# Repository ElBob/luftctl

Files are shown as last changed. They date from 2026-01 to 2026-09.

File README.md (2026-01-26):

# luftctl

Small ESP32-C3 controller board to power two 12V PWM fans from a single USB-C plug.



## hardware

Schematic and PCB design can be found in [`hardware/`](hardware/). It is a KiCAD 6 project.

The schematic is available as [a PDF](schematic.pdf).

For hand-soldering, you can use the [interactive BOM viewer](hardware/ibom.html).

## firmware

### micropython

The first simple test just loops through {`5V/off`, `5V/on`, `12V/off`, `12V/on`} with every button press.

Download MicroPython from [micropython.org/download/esp32c3-usb/](https://micropython.org/download/esp32c3-usb/) and flash it with:

```
esptool.py --chip esp32c3 --port /dev/ttyACM0 erase_flash
esptool.py --chip esp32c3 --port /dev/ttyACM0 --baud 460800 write_flash -z 0x0 esp32c3-*.bin
```

Then install a virtualenv with `adafruit-ampy` and upload the [`main.py`](main.py):

```
ampy -p /dev/ttyACM0 put main.py
ampy -p /dev/ttyACM0 reset --hard
```

The red LED will blink upon every state change.

### esphome

Since the ESP32-C3 is easily supported by ESPHome, you can also add it in your HomeAssistant automation using the [provided example YAML](esphome/luftctl.yaml).

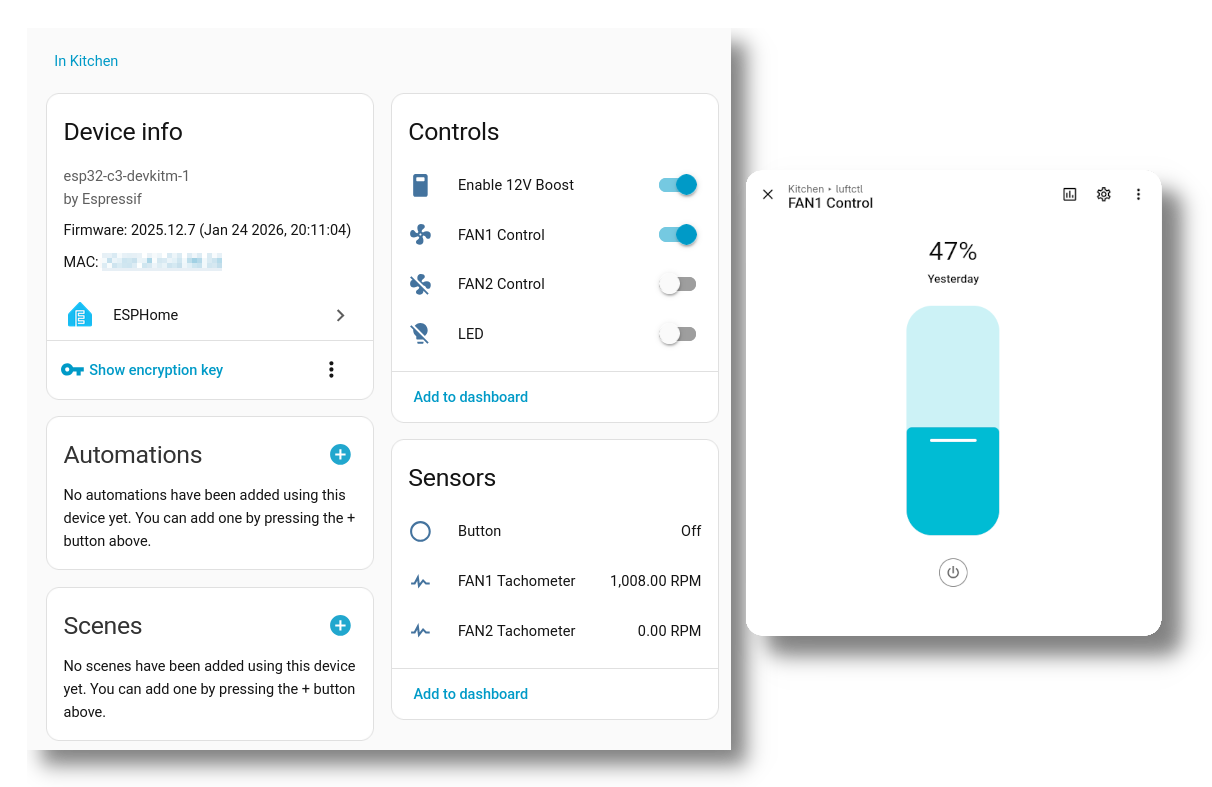
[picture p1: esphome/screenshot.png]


## images











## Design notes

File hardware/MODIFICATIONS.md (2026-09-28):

# luftctl — design change: USB‑C PD 12 V input + GPIO breakout

## ✅ Implementation status (branch `usbc-pd-12v-and-gpio-breakout`)

**Both changes are implemented in the schematic** (`luftctl.kicad_sch`) and
verified: the netlist was re-exported and every rail/net checked, and ERC is at
the project's baseline (the remaining violations are pre‑existing
`lib_symbol_mismatch` from this project's custom symbols, plus one benign
"power pin not driven" on the CH224K's self‑generated VDD). See the rendered
result in **`luftctl-modified-schematic.pdf`**. Firmware (`main.py`,
`esphome/luftctl.yaml`) is updated.

Done in the schematic:
- Removed: U1 (boost), L1, D1, R1, R2, C6, R4/R5 (CC pull‑downs), U2 (LDO).
- Added: **U5 CH224K** PD trigger, **U6 LMR51420** buck, L2 (10 µH), R11/R12
  (buck FB divider), R13/R14/R15 (CH224K CFG straps), C12 (boot), C13 (buck Vin),
  C14 (buck Vout), C15 (CH224K VDD), **J6** 1×8 GPIO breakout.
- +5 V rail merged into +12 V; **J2/J3 power pins moved to +3V3**; fans stay on +12 V.
- Net `12V_EN` renamed **GPIO3** and broken out on J6 (R3 remains as a harmless
  10 kΩ pull‑down on that pin — delete it if you don't want one).

**Two remaining steps must be done in the KiCad GUI (can't be done headless):**
1. Open the PCB → **Tools ▸ Update PCB from Schematic** (one click). This pulls in
   J6, U5, U6, L2, R11–R15, C12–C15 with correct nets and drops the removed parts.
2. **Place and route** the new parts — especially the buck's switching loop
   (Cin→VIN/GND tight, short SW node, FB away from SW) per the layout notes below.
   Then re‑run the JLCPCB `jlcpcb/` generation (those files are pre‑mod).

## Datasheet-confirmed values (researched + cross-verified, high confidence)

### CH224K — request 12 V  (source: WCH CH224 datasheet V2.0, §6.2 / §7.1)

Standalone I/O-strap truth table (**CH224K**, not the CH224A/Q table):

| CFG1 | CFG2 | CFG3 | Request |
|:----:|:----:|:----:|:---|
| 1 | X | X | 5 V |
| 0 | 0 | 0 | 9 V |
| **0** | **0** | **1** | **12 V** |
| 0 | 1 | 1 | 15 V |
| 0 | 1 | 0 | 20 V |

`0` = strap to GND, `1` = HIGH. **CH224K has NO internal pull-ups on CFG2/CFG3**,
so a `1` must be pulled up externally — it cannot float.

> ⚠️ **Two bugs in the current netlist — the board as drawn would give 9 V and a dead chip:**
> 1. **R15/CFG3 is strapped to GND (=0) → selects 9 V, not 12 V.** CFG3 must be
>    **pulled HIGH to VDD via ~10 kΩ** (the reference schematic value), not tied to GND.
>    Keep R13/CFG1→GND and R14/CFG2→GND (both `0`, correct).
> 2. **VDD (pin 1) is not powered** — it only has C15 (1 µF) to GND. VDD must be fed
>    **from VBUS through a ~1 kΩ series resistor** (reference-schematic value; VDD is a
>    ~3.6 V shunt-regulated logic rail). Without it the chip never runs. This is the
>    "power pin not driven" ERC warning. Add R_VDD (VBUS→VDD, 1 kΩ).
> 3. **VBUS (pin 8) sense** should reach the pin through a **series resistor**, not a
>    direct tie to the 12 V rail (per the reference schematic).
>
> So: R13 = 0 Ω (CFG1→GND) ✔, R14 = 0 Ω (CFG2→GND) ✔, **R15 = 10 kΩ pull-up CFG3→VDD**,
> **add R_VDD = 1 kΩ VBUS→VDD**, and a series R on the VBUS-sense pin. PG/DP/DM stay NC.
> (I2C config is not available on CH224K.)

### LMR51420 — set 3.3 V  (source: TI SLUSEF6C, §7.6 / §9.2.2.2, Eq. 9)

- **VREF = 0.600 V**; `Vout = VREF · (1 + RFBT/RFBB)`.
- TI's 3.3 V typical value: **RFBT (R11) = 100 kΩ, RFBB (R12) = 22.1 kΩ → 3.315 V**.
- **Current board R11 = 100 kΩ / R12 = 22 kΩ → 3.327 V (+0.8 %)** — in tolerance and
  fine to leave; swap R12 to **22.1 kΩ (E96)** for the datasheet-exact +0.45 %.
- **No feedforward cap** — the LMR51420 is internally compensated (do NOT reuse the
  old boost's 220 pF C6).

### Footprint

- **CH224K** is `SSOP-10-1EP_3.9x4.9mm` (KiCad default here); confirm against the exact
  package you order. Buck is SOT-23-6; L2 reuses the SRN6045 6×6 footprint.

---

Engineering change spec for two modifications:

1. **Power the fans from 12 V negotiated over USB‑C Power Delivery** instead of
   boosting 5 V → 12 V on‑board.
2. **Break out a few spare GPIOs** on an easy 2.54 mm Dupont header.

> This document is the schematic/BOM change list. The symbol placement, wiring,
> and PCB routing still need to be done in the KiCad GUI — switching‑regulator
> layout (buck loop, feedback, thermals) must not be done blind. Everything you
> need to execute it is below.

## ⚠️ Hard requirement for mod 1

12 V over USB‑C **only works from a USB‑C Power‑Delivery source** (a PD charger /
PD power bank). A plain 5 V USB port or an A‑to‑C cable **cannot** supply 12 V —
the board will get no fan power in that case. After the PD contract is made,
**VBUS itself becomes 12 V**, which is why the on‑board boost is removed and a
buck is added for the 3.3 V logic (a 5 V→3.3 V LDO can't run from 12 V).

## Decisions taken

| Topic | Choice |
|---|---|
| 12 V source | **CH224K** PD trigger, fixed 12 V, standalone (no firmware) |
| 3.3 V logic supply | **Single 12 V→3.3 V buck** (LMR51420); J2/J3 power pin becomes 3.3 V |
| Fan 12 V gating | **Removed** — 12 V always on, fans controlled by PWM only; IO3 freed |
| GPIO breakout | 1×8 header: **IO2, IO3, IO8, IO20/RX, IO21/TX, 3V3, GND, GND** |

---

## New power architecture

```
                              CH224K (U5)                 LMR51420 buck (U6)
 USB-C ─┬─CC1───────────────► CC1                       ┌──► VIN ──SW──L2(10µH)──┬──► +3V3 ─► ESP32 + pullups + J2/J3 pwr
 (J1)   ├─CC2───────────────► CC2                       │                        │
        │                     CFG1/2/3 ─(strap 12V)     │              R_top ─────┤
        ├─VBUS ──FB1──┬───────► VBUS  ───────────────────┤              FB ◄───────┤
        │             │        PG ─(opt, NC)             │              R_bot ──GND │
        │             │        GND                       │   EN─(pullup to VIN)     │
        │             ├──────────────────────────────────┘   BST─Cboot─SW           │
        │             │                                                              │
        │             ├──► +12V ──► J4.2 / J5.2  (fan power, always on)              │
        │             └──► Cbulk (≥10µF, ≥25V) + Cin_buck (reuse C1/C7 4.7µF/50V)    │
        └─D+/D- ──► U3 (USBLC6 ESD) ──► ESP32 IO19/IO18   (unchanged)
```

*The old +5 V rail no longer exists.* "VBUS" and "+12 V" are the same
post‑negotiation rail; keep FB1 as an input EMI bead (verify its 2 A rating vs
your fans' stall current, or short it out).

### Remove

| Ref | Part | Why |
|---|---|---|
| U1 | LMR62014XMF boost | 12 V now comes from PD, not a boost |
| D1 | 1N5819 (boost catch diode) | boost gone |
| R1, R2 | 113 kΩ / 13 kΩ (boost FB divider) | boost gone (footprints reusable for buck FB, new values) |
| C6 | 220 pF (boost feed‑forward) | boost gone |
| R4, R5 | 5.1 kΩ CC pull‑downs | CH224K provides its own CC termination/BMC; leaving Rd would force a 5 V‑only contract |
| U2 | MIC5504‑3.3 LDO | can't run from 12 V; replaced by buck |

### Repurpose (reuse footprint / net rework, don't delete)

| Ref | Was | Now |
|---|---|---|
| L1 | 10 µH boost inductor (SRN6045, +5V↔SW) | buck inductor **L2** between buck SW and +3V3 (same SRN6045 6×6 pad; keep 10 µH) |
| C8 | 10 µF boost output cap on +12V | +12 V bulk cap on VBUS (12 V) |
| C1, C7 | 4.7 µF/50 V input caps on +5V | buck VIN caps on +12 V (50 V rating is fine) |
| C10 | 10 µF on +3V3 | buck output cap on +3V3 (add a 22 µF if ripple needs it) |
| FB1 | bead VBUS→+5V | bead VBUS→+12V input filter (or DNP) |

### Add

| Ref | Part | Function | Notes |
|---|---|---|---|
| U5 | **CH224K** PD sink controller | negotiate fixed 12 V | CC1/CC2 → J1 CC; VBUS sense → VBUS; strap CFG1‑3 for 12 V **per datasheet** (12 V ≈ CFG1=GND, CFG2=GND, CFG3=high — *verify against CH224K Table*); 100 nF on VDD; PG open‑drain optional (leave NC or route to a test point) |
| U6 | **LMR51420** buck (SOT‑23‑6) | 12 V → 3.3 V logic | VIN=+12V, EN pulled up to VIN, SW→L2→+3V3, FB divider to +3V3, Cboot ~100 nF (BST–SW). Set 3.3 V via FB divider: `Vout = Vref·(1+Rtop/Rbot)`, **confirm Vref (~0.6–0.8 V)** from datasheet; e.g. with Vref 0.8 V use Rbot 10 kΩ, Rtop 31.6 kΩ (reuse R1/R2 pads) |
| J6 | **1×8 2.54 mm header** | GPIO breakout (Dupont) | pinout below |
| Cboot, Cin/Cout | small ceramics | buck support | per LMR51420 datasheet (typ. 100 nF boot, 10 µF in, 22 µF out) |

---

## GPIO breakout header (J6)

1×8, 2.54 mm, Dupont‑compatible. Suggested pinout:

| Pin | Signal | ESP32‑C3 | Notes |
|----:|---|---|---|
| 1 | **3V3** | — | logic supply out (from buck), keep peripheral load small |
| 2 | **GND** | — | |
| 3 | **IO2** | GPIO2 | spare; has 10 kΩ boot‑strap pull‑up (must be high at reset) |
| 4 | **IO3** | GPIO3 | freed by removing the 12 V enable |
| 5 | **IO8** | GPIO8 | spare; has 10 kΩ boot‑strap pull‑up (must be high at reset) |
| 6 | **RX** | GPIO20 | UART0 RX (also on JST J2) |
| 7 | **TX** | GPIO21 | UART0 TX (also on JST J2) |
| 8 | **GND** | — | 2nd ground for jumpers |

Connect each pin with a short wire stub + a **local label** matching the existing
net name (`GPIO2`, `12V_EN`→rename to `GPIO3`, `GPIO8`, `RXD`, `TXD`, `+3V3`,
`GND`); connectivity is by label, so it nets correctly regardless of placement.
**Strapping caution:** IO2 and IO8 (and IO9) must not be pulled low at reset —
don't hang a hard pull‑down or a bus that idles low on IO2/IO8.

---

## Part selection & availability (vs jlcparts snapshot 2026‑09‑24)

| Ref | Recommended part | LCSC | In‑stock? |
|---|---|---|---|
| U5 | CH224K (WCH) | — | **Not in this snapshot.** In‑stock drop‑in: **HUSB238** `C7471904` (Hynetek, DFN‑10, 9,642). HUSB238 wants I2C or a strap to select 12 V — for a truly no‑firmware build prefer CH224K (re‑check a live jlcparts build), else set 12 V over I2C from the ESP at boot. |
| U6 | LMR51420YFDDCR (TI, SOT‑23‑6, 36 V/2 A) | `C7296200` | ✅ 6,432 |
| L2 | 10 µH power inductor | reuse L1 SRN6045 (`C17236259`, low stock 17) or 4×4 `C6808084` ANR4018T100M (37 k) if you change the footprint | ⚠ |
| J6 | 1×8 2.54 mm header | `C7501266` (ZX‑PZ2.54‑1‑8PZZ) | ✅ 2,311 |

Buck support passives (Cboot/Cin/Cout, FB resistors) and the kept passives are
covered by the existing 0805 assignments in `jlcpcb/VERIFICATION.md`. **Regenerate
the JLCPCB BOM/CPL after the KiCad edits** — the current files in `jlcpcb/` reflect
the pre‑mod board.

---

## PCB / layout notes

- **Buck (U6):** tight input‑cap loop (Cin → VIN/GND), short SW node, keep FB
  divider away from SW, single‑point ground for the power stage. Follow the
  LMR51420 datasheet layout example. The freed U1/L1/D1 area gives you room.
- **CH224K (U5):** place near J1; CC1/CC2 short and direct to the connector;
  bulk cap on VBUS close to the connector for fan inrush.
- **12 V trace to fans (J4/J5):** widen for fan stall current (both fans + inrush).
- **Delete** the R4/R5 pads and the boost components; **re‑net** J2.2/J3.2 from
  +5V to +3V3.

---

## Firmware changes (done in this repo)

- `main.py` and `esphome/luftctl.yaml`: the GPIO3 "enable 12 V" control is
  removed (12 V is always present now); fans are off at PWM = 0 %. GPIO2/3/8 and
  UART are noted as available on J6. See those files.
- Note for connected peripherals: **J2/J3 power pin is now 3.3 V, not 5 V.**

---

## Module sourcing (U4)

- **Part: `ESP32-C3-WROOM-02-N4`, LCSC `C2934560`** — 9,524 in stock at JLCPCB
  assembly, min order **1**, ~$3.29 @ qty 1. This is the **PCB‑antenna** variant,
  which matches the original board's footprint (`RF_Module:ESP-WROOM-02`) and its
  antenna keep‑out — a **drop‑in** with **no re‑layout, no firmware change, and no
  external antenna** required.
- Do **not** use the `-02U` (U.FL) variant: it needs an external antenna and only
  ships as a high‑minimum pre‑order. All ESP32‑C3‑WROOM‑02/MINI‑1 and S3‑WROOM‑1
  modules are 0 immediate JLCPCB assembly stock as pre‑orders (30–100 unit mins);
  `C2934560` is the only low‑minimum in‑stock C3 module.
- **Antenna keep‑out (verified):** the module's PCB‑antenna region (x≈136.3–164.4,
  y≈50.0–56.1) is a rule area on **both F.Cu and B.Cu** (no zone fill, no tracks,
  no vias). The added B.Cu ground plane is correctly carved out of it; no tracks or
  vias intrude the antenna rectangle. Keep U4's antenna edge at the board edge.

---

## BOM sourcing — use JLCPCB **Basic** parts for jellybeans

The first BOM pass assigned **Extended** parts to every passive (an artifact of a
sparse parts-DB snapshot). Extended parts each carry a per-type loading fee, a reel
MOQ (~20–50), and count against the Economic-tier extended-part limit. All passives
have been re-sourced to **Basic** parts (no fee, no MOQ, buy exactly what's needed).
Sourced via `jlcsearch.tscircuit.com` (`is_basic=true`, in-stock, 0805):

| Value | Refs | LCSC (Basic) | MFR / notes |
|---|---|---|---|
| 10 kΩ | R3,R6,R7,R8,R15 | **C17414** | 0805W8F1002T5E, 1% |
| 2.2 kΩ | R10 | **C17520** | 0805W8F2201T5E |
| 100 kΩ | R11 | **C149504** | 0805W8F1003T5E (buck FB top) |
| 22 kΩ | R12 | **C17560** | 0805W8F2202T5E (buck FB bot) |
| 1 kΩ | R16 | **C17513** | 0805W8F1001T5E (CH224K VDD feed) |
| 680 Ω | R9 | **C17798** | was 660 Ω; nearest Basic E24, D2 LED limit (~1.9 mA) |
| 4.7 µF 25 V | C1,C7 | **C1779** | CL21A475KAQNNNE X5R (12 V rail) |
| 1 µF 50 V | C3,C4,C15 | **C28323** | CL21B105KBFNNNE X7R |
| 100 nF 50 V | C5,C9,C11,C12 | **C49678** | CC0805KRX7R9BB104 |
| 10 µF 25 V | C8,C10,C13 | **C15850** | CL21A106KAYNNNE X5R (12 V rail) |
| 22 µF 25 V | C14 | **C45783** | CL21A226MAQNNNE X5R (3V3 rail) |
| Red LED | D2,D3 | **C84256** | NCD0805R1 |

**Switches SW1/JP1:** re-spun from `SW_SPST_PTS810` (OOS) to Basic tact **C231329**
(Omron B3U-1000P, 3×2.5 mm) on footprint `Button_Switch_SMD:SW_SPST_B3U-1000P`;
board re-routed locally. (The larger XKB TS-1187A was tried first but its ±3 mm
pads collided with D2/R9 — B3U's ±1.7 mm pads fit the PTS810 envelope cleanly.)
**J2/J3 JST-SH:** **C160404** (SM04B-SRSS-TB, side-entry, fits existing footprint).
**U5 CH224K:** **C970725** — only listing; JLCPCB main stock 0 but 114 idle-parts
stock (covers a 5-board run).
**J4/J5 fan + J6 breakout headers:** removed from the assembly BOM (hand-soldered).

Remaining **Extended** parts (no viable Basic swap — verified): U4 ESP32
(C2934560), U6 LMR51420 buck (C7296200 — Basic regulators are LDOs, too lossy),
U3 USBLC6 (C6807798 — no Basic ESD array), U5 CH224K, J1 USB-C (C165948 — no Basic
USB-C), J2/J3 JST-SH (all Extended), FB1 ferrite (C85840 Murata BLM21PG221SN1D, 2 A — Basic 0805 beads max 800 mA),
L2 inductor (C2046332 Bourns SRN6045TA-100M, the footprint's exact part). SW1/JP1 are the only IC/connector/
switch line that could go Basic.

---

## Order plan (current)

**Full JLCPCB assembly, 5 boards, Economic.** The draft order is saved in the
JLCPCB account (SMT order `pcbFileNo=17fc5232720c43a29fb01457f2768e8f`). It has not
been placed. BOM `luftctl-mod-bom.csv` (25 lines) and CPL `luftctl-mod-cpl.csv`
(38 placements) match 1:1. Hand-soldered by the owner, not in the BOM/CPL:
J4/J5 fan headers (keyed 4-pin, e.g. Molex 47053-1000) and J6 (1x8 2.54 mm header).

## To do before ordering

1. **Wait for CH224K (U5, C970725) to restock.** JLCPCB assembly stock is 0
   (5 short). No Basic substitute exists, and in-stock alternatives (HUSB238,
   IP2721, AP33772) would mean redesigning the U5 section, so we're waiting.
2. **Re-upload the fab files** to the draft order once U5 is back: gerber
   `luftctl-modified-gerber.zip`, `luftctl-mod-bom.csv`, `luftctl-mod-cpl.csv`.
   In JLCPCB's placement preview, check that D4's cathode band faces J1 (pad 1,
   the VBUS side). A reversed TVS would short VBUS to GND.

## Done (2026-09-27)

- **Switch inputs J7 (GPIO3 + GND) and J8 (GPIO8 + GND):** 2-pin 2.54 mm headers
  standing vertically along the USB-C (right) edge, one above and one below the
  port (symmetric about the centre line; GND pins nearest USB-C). Board extended
  3 mm to the right for them: **59.75 x 32.1 mm**.
  Silkscreen "IO3"/"IO8"; pin 1 (square) is the GPIO, pin 2 is GND. ESPHome:
  `Switch 1`/`Switch 2` binary sensors with internal pull-ups (see yaml). GPIO8 is
  a strapping pin but only matters for download mode (don't hold that switch
  closed while flashing with BOOT).
- **Removed R3** (10 kΩ GPIO3 pull-down left over from the old 12 V-enable); it
  would have held the switch input low.
- **J6 back to 8 pins:** 3V3, GND, IO2, RX, TX, GND, SDA, SCL.
- **CH224K CFG1/CFG2 tied straight to GND** (R13/R14 0 Ω straps removed) — same
  12 V setting, two fewer parts. Changing the PD voltage later means cutting a
  trace/adding a strap instead of swapping a resistor.
- Added 0.5 mm no-track strips along all board edges so routing can't crowd the
  edge; this also cleared the old FAN1_Tacho edge violation. DRC: 0 unconnected,
  only J4/J5 hole spacing and courtyard-margin warnings remain.

- **Compact outline: 56.7 x 32.1 mm** (was 56.7 x 43.1). Board is centred
  vertically on the two fan headers (y = 62.45); USB-C (J1) moved down 5 mm to the
  same centre line. Top edge moved up 2.5 mm to keep it symmetric; that strip is
  inside the antenna keep-out (now y 46.75-56.1, both layers).
  - Bottom edge: J6 with pin labels above the pins.
  - Buck (U6, L2, C12-C14, R11, R12) beside SW1; CH224K group (U5, R13-R15, C15)
    under J1; D4 and R16 above J1.
  - Removed TP1 and TP4 (12 V is on the fan headers/TP2, GND on J6).
    "2022 ansemjo" moved to the back silkscreen.
  - Ground is now poured on **both** layers with a via-stitching grid; DRC
    0 unconnected, no shorts/clearance errors (remaining items are the
    pre-existing FAN1_Tacho edge track, J4/J5 hole spacing, courtyard margins).
  - Small-part reference designators in the dense clusters are hidden on the
    silkscreen (fab/assembly use the BOM/CPL designators).
  - **Check in JLCPCB placement preview:** U5 (CH224K) rotation, since it has not
    been previewed yet (it was out of stock).

- **Removed J2 (UART) and J3 (I2C) JST-SH connectors.** UART was already on
  J6 and flashing/logs go over native USB. SDA (GPIO0) and SCL (GPIO1) moved to
  J6, which is now a 1x10 header: 3V3, GND, IO2, IO3, IO8, RX, TX, GND, SDA, SCL
  (pin labels on the silkscreen). Drops the C160404 Extended line.

- **L2 -> C2046332, FB1 -> C85840.** The previous listings (C17236259,
  C6750922) have no JLCPCB/EasyEDA footprint data, so the placement preview
  couldn't place them. Same footprints; BOM-only change.
- **Assembly tip:** JLCPCB auto-unchecks BOM lines that share a part number
  (D2/D3, J2/J3, JP1/SW1) with a "multiple lines matched to the same part"
  warning. Re-tick them every time the BOM is re-processed.

- **Buttons SW1/JP1** swapped from B3U-1000P (C231329, Extended) to
  **TS-1088-AR02016 (C720477, Basic)**, footprint `SW_SPST_TS-1088-xR020`.
- **U3 USBLC6 pin 5 disconnected from VBUS** (now no-connect in the schematic and
  unconnected on the board). VBUS is 12 V after PD negotiation and the USBLC6
  supply-pin clamp starts conducting around 6 V. Pin 5 is left floating rather
  than tied to +3V3, because CC1/CC2 (U3 pins 1/6) sit near 5 V and would leak
  into the 3.3 V rail. D+/D- keep their ESD protection (needed for flashing the
  ESP32-C3 over native USB).
- **Added D4, SMF15A TVS (C19077509, SOD-123FL, 15 V standoff)** from VBUS to
  GND, placed above J1 with a via to the B.Cu ground plane. Extended part, but the
  button swap removed one, so the Extended count is unchanged.
- Re-routed locally (existing tracks locked). DRC: 0 unconnected, no shorts or
  clearance errors; the 12 remaining items are the pre-existing ones (FAN1_Tacho
  near the board edge, J4/J5 hole spacing, courtyard margins). Board matches the
  schematic netlist on all 153 pads. Antenna keep-out still clear.

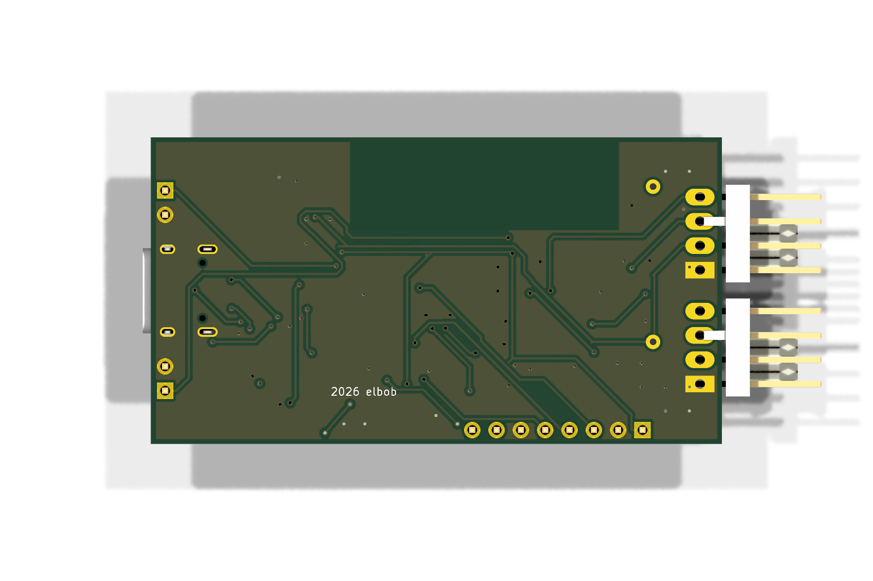
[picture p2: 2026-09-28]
hardware/jlcpcb/production_modified/render-bottom.png

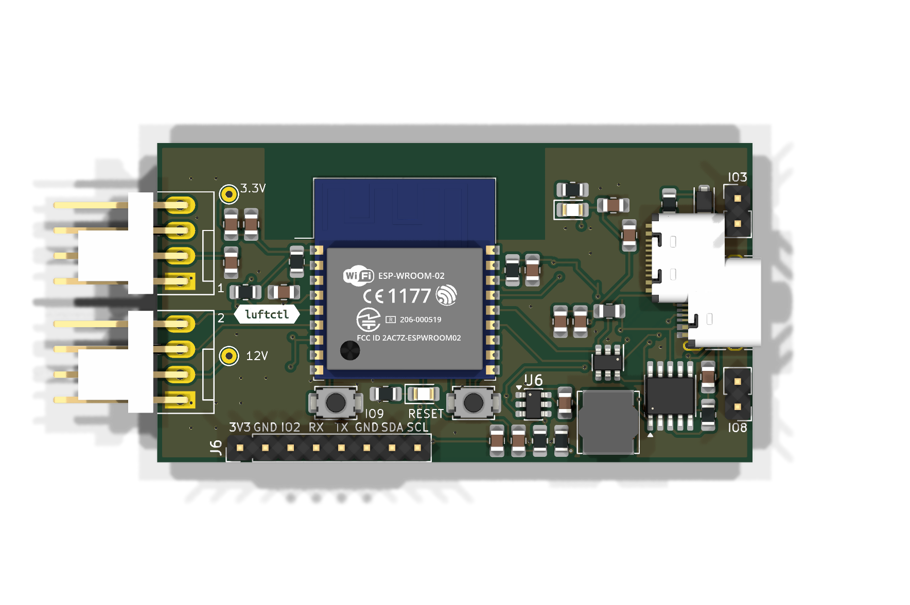
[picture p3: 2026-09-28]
hardware/jlcpcb/production_modified/render-top.png

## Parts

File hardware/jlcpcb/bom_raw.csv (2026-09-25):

Designator | Comment | Footprint | MPN | Manufacturer
A1 | 2022 | ansemjo:ahoi
C1,C7 | 4.7µF | Capacitor_SMD:C_0805_2012Metric_Pad1.18x1.45mm_HandSolder
C3,C4 | 1µF | Capacitor_SMD:C_0805_2012Metric_Pad1.18x1.45mm_HandSolder
C5,C9,C11 | 100nF | Capacitor_SMD:C_0805_2012Metric_Pad1.18x1.45mm_HandSolder
C6 | 220pF | Capacitor_SMD:C_0805_2012Metric_Pad1.18x1.45mm_HandSolder
C8,C10 | 10µF | Capacitor_SMD:C_0805_2012Metric_Pad1.18x1.45mm_HandSolder
D1 | 1N5819 | Diode_SMD:D_SOD-123
D2 | USR | LED_SMD:LED_0805_2012Metric_Pad1.15x1.40mm_HandSolder
D3 | PWR | LED_SMD:LED_0805_2012Metric_Pad1.15x1.40mm_HandSolder
FB1 | 220ΩZ | Inductor_SMD:L_0805_2012Metric_Pad1.15x1.40mm_HandSolder
J1 | USB_C_Receptacle_USB2.0 | Connector_USB:USB_C_Receptacle_HRO_TYPE-C-31-M-12
J2 | UART | Connector_JST:JST_SH_SM04B-SRSS-TB_1x04-1MP_P1.00mm_Horizontal
J3 | I2C | Connector_JST:JST_SH_SM04B-SRSS-TB_1x04-1MP_P1.00mm_Horizontal
J4,J5 | PWM Fan | Connector:FanPinHeader_1x04_P2.54mm_Vertical
JP1 | Bootloader | Button_Switch_SMD:SW_SPST_PTS810
L1 | 10µH | Inductor_SMD:L_Bourns_SRN6045TA
R1 | 113kΩ | Resistor_SMD:R_0805_2012Metric_Pad1.20x1.40mm_HandSolder
R2 | 13kΩ | Resistor_SMD:R_0805_2012Metric_Pad1.20x1.40mm_HandSolder
R3,R6,R7,R8 | 10kΩ | Resistor_SMD:R_0805_2012Metric_Pad1.20x1.40mm_HandSolder
R4,R5 | 5.1kΩ | Resistor_SMD:R_0805_2012Metric_Pad1.20x1.40mm_HandSolder
R9 | 660Ω | Resistor_SMD:R_0805_2012Metric_Pad1.20x1.40mm_HandSolder
R10 | 2.2kΩ | Resistor_SMD:R_0805_2012Metric_Pad1.20x1.40mm_HandSolder
SW1 | Reset | Button_Switch_SMD:SW_SPST_PTS810
TP1,TP2,TP3,TP4 | Test | TestPoint:TestPoint_THTPad_D1.5mm_Drill0.7mm
U1 | LMR62014XMF | Package_TO_SOT_SMD:SOT-23-5
U2 | MIC5504-3.3YM5 | Package_TO_SOT_SMD:SOT-23-5
U3 | USBLC6-4SC6 | Package_TO_SOT_SMD:SOT-23-6 | USBLC6-4SC6 | ST Microelectronic
U4 | ESP32-C3-WROOM-02 | RF_Module:ESP-WROOM-02

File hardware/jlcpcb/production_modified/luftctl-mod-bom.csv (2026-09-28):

Comment | Designator | Footprint | LCSC Part #
4.7µF | C1,C7 | Capacitor_SMD:C_0805_2012Metric_Pad1.18x1.45mm_HandSolder | C1779
1µF | C3,C4,C15 | Capacitor_SMD:C_0805_2012Metric_Pad1.18x1.45mm_HandSolder | C28323
100nF | C5,C9,C11,C12 | Capacitor_SMD:C_0805_2012Metric_Pad1.18x1.45mm_HandSolder | C49678
10µF | C8,C10,C13 | Capacitor_SMD:C_0805_2012Metric_Pad1.18x1.45mm_HandSolder | C15850
22µF | C14 | Capacitor_SMD:C_0805_2012Metric_Pad1.18x1.45mm_HandSolder | C45783
USR | D2 | LED_SMD:LED_0805_2012Metric_Pad1.15x1.40mm_HandSolder | C84256
PWR | D3 | LED_SMD:LED_0805_2012Metric_Pad1.15x1.40mm_HandSolder | C84256
SMF15A | D4 | Diode_SMD:D_SOD-123F | C19077509
220ΩZ | FB1 | Inductor_SMD:L_0805_2012Metric_Pad1.15x1.40mm_HandSolder | C85840
USB_C_Receptacle_USB2.0 | J1 | Connector_USB:USB_C_Receptacle_HRO_TYPE-C-31-M-12 | C165948
Bootloader | JP1 | Button_Switch_SMD:SW_SPST_TS-1088-xR020 | C720477
10µH | L2 | Inductor_SMD:L_Bourns_SRN6045TA | C2046332
10kΩ | R6,R7,R8,R15 | Resistor_SMD:R_0805_2012Metric_Pad1.20x1.40mm_HandSolder | C17414
680Ω | R9 | Resistor_SMD:R_0805_2012Metric_Pad1.20x1.40mm_HandSolder | C17798
2.2kΩ | R10 | Resistor_SMD:R_0805_2012Metric_Pad1.20x1.40mm_HandSolder | C17520
100kΩ | R11 | Resistor_SMD:R_0805_2012Metric_Pad1.20x1.40mm_HandSolder | C149504
22kΩ | R12 | Resistor_SMD:R_0805_2012Metric_Pad1.20x1.40mm_HandSolder | C17560
1kΩ | R16 | Resistor_SMD:R_0805_2012Metric_Pad1.20x1.40mm_HandSolder | C17513
Reset | SW1 | Button_Switch_SMD:SW_SPST_TS-1088-xR020 | C720477
USBLC6-4SC6 | U3 | Package_TO_SOT_SMD:SOT-23-6 | C6807798
ESP32-C3-WROOM-02-N4 | U4 | RF_Module:ESP-WROOM-02 | C2934560
CH224K | U5 | Package_SO:SSOP-10-1EP_3.9x4.9mm_P1mm_EP2.1x3.3mm | C970725
LMR51420YFDDCR | U6 | Package_TO_SOT_SMD:SOT-23-6 | C7296200

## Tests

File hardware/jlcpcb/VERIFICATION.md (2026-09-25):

# luftctl — JLCPCB assembly files & parts verification

Generated 2026-09-24 from `hardware/luftctl.kicad_pcb` / `.kicad_sch`
(KiCad 6 project) using `kicad-cli` 10.0.6.

## Output files (`production_files/`)

| File | Purpose |
|---|---|
| `luftctl-bom.csv` | JLCPCB BOM (`Comment, Designator, Footprint, LCSC Part #`) |
| `luftctl-top-pos.csv` | JLCPCB CPL / placement (`Designator, Mid X, Mid Y, Layer, Rotation`), **rotation-corrected**, mm |
| `luftctl-gerber.zip` | Single-board Gerbers + PTH/NPTH Excellon drill (RS-274X, mm, aux origin) |

Non-assembly items are excluded from both BOM and CPL: `A1` (silk logo) and
`TP1–TP4` (test-point THT pads). All 36 placed parts are on the **Top** layer.

## Parts verification against the jlcparts database

Verified against the canonical jlcparts SQLite snapshot
(`yaqwsx.github.io/jlcparts/data/cache.*`), downloaded 2026-09-24; the snapshot's
`fetched_at` timestamps span 2026-09-14 → 2026-09-24. "In stock" = `stock > 0`.

> ⚠️ **Snapshot caveat.** This particular jlcparts build is sparse: every LCSC
> code is ≥ C6374508 (no classic low C-numbers), the companion `lcsc_components`
> table is empty, and only ~1,500 resistors and ~1,500 capacitors are in stock
> across the whole catalog. Classic JLC "Basic" parts (e.g. C1525, ESP32-C3
> C2934569) are entirely absent. As a result several perfectly ordinary parts
> show **no in-stock match in this DB** — that reflects the snapshot, not
> necessarily real-world JLCPCB availability. Re-verify against a live jlcparts
> build before ordering. All library types resolved to "Extended" in this snapshot.

### 15 line items with a verified in-stock LCSC match

| Designator | Value | LCSC | MPN | Stock | Notes |
|---|---|---|---|---|---|
| C1,C7 | 4.7µF | C7472969 | HGC0805R5475K500NSLJ | 350,459 | X5R 50V |
| C3,C4 | 1µF | C6641028 | 08051C105K4T2A | 11,844 | X7R 100V |
| C5,C9,C11 | 100nF | C7503487 | CGA0805X7R104K101KT | 55,238 | X7R 100V |
| C6 | 220pF | C7393918 | TCC0805COG221J501BT | 13 | C0G 500V — **low stock**, only option |
| C8,C10 | 10µF | C16194907 | CL21Y106KABVPNE | 3,824 | X7S 25V (adequate for 12V rail) |
| D1 | 1N5819 | C6562211 | 1N5819W SL | 694 | Schottky, SOD-123 |
| D2 | USR | C7496834 | P2-0805R1TS2 | 861,815 | Red LED 0805 — colour is a design choice |
| D3 | PWR | C7496834 | P2-0805R1TS2 | 861,815 | Red LED 0805 — colour is a design choice |
| FB1 | 220ΩZ | C6750922 | BBPY00201209221Y00 | 2,895 | Ferrite bead 220Ω@100MHz, 2A |
| J4,J5 | PWM Fan | C7501262 | ZX-PZ2.54-1-4PZZ | 39,729 | 1×4 2.54mm header, THT (manual solder) |
| L1 | 10µH | C17236259 | SRN6045HA-100M | 17 | **Low stock**; SRN6045 family per design |
| R3,R6,R7,R8 | 10kΩ | C7468432 | FRQ0805J103 | 28,237 | 0805 ±5% |
| R4,R5 | 5.1kΩ | C7471596 | TE05H5101DT | 470 | 0805 ±0.5% — only option (USB-C CC pulldowns) |
| R10 | 2.2kΩ | C7471245 | FRQ0805F2201 | 49 | 0805 ±1% — **low stock** |
| U3 | USBLC6-4SC6 | C6807798 | USBLC6-2SC6-FS | 1,269 | **Functional equiv.** The schematic's "USBLC6-**4**SC6" is nonstandard; ST's real part is USBLC6-**2**SC6 (same SOT-23-6 USB ESD array). Verify pinout. |

### 11 line items with NO in-stock match in this snapshot (need manual sourcing)

| Designator | Value | Why | Suggested next step |
|---|---|---|---|
| R1 | 113kΩ | No in-stock 0805 (none at any package in this DB) | Source 113k 0805 1%, or split/adjust the feedback divider |
| R2 | 13kΩ | No in-stock **0805** (only 0402/1206 in stock) | Source 13k 0805 |
| R9 | 660Ω | No in-stock 0805 (none at any package in this DB) | 660Ω is unusual; consider 649Ω(E96)/680Ω if the LED current allows |
| J1 | USB-C `TYPE-C-31-M-12` | Exact HRO part OOS | Nearest in-stock 16-pin Type-C: **C7431072** "TYPE-C 16PIN 5A 143" — **verify footprint/pads** vs `USB_C_Receptacle_HRO_TYPE-C-31-M-12` before use |
| J2 | UART (JST SH SM04B-SRSS-TB) | OOS | Nearest 1.0mm 4P SMD: **C7430446** ZX-SH1.0-4PWT — verify footprint |
| J3 | I2C (JST SH SM04B-SRSS-TB) | OOS | same as J2 |
| JP1 | Bootloader (PTS810) | C&K PTS810 SMD tact switch absent | Source a PTS810-compatible SMD tact switch |
| SW1 | Reset (PTS810) | same as JP1 | same |
| U1 | LMR62014XMF | TI boost converter absent | Source LMR62014 (SOT-23-5) |
| U2 | MIC5504-3.3YM5 | Microchip 3.3V LDO absent | Source MIC5504-3.3 (SOT-23-5) |
| U4 | ESP32-C3-WROOM-02 | Only `-N16` variant present, **stock 0** | Source the module (main IC) — critical |

## Placement rotation corrections

Corrections applied per the de-facto standard database
(`matthewlai/JLCKicadTools` `cpl_rotations_db.csv`). For every top-layer part:
`JLC_rotation = (kicad_rotation + correction) mod 360`, plus any X/Y offset
(none applied here). Last matching regex wins.

**3 footprint types were corrected (7 placements):**

| Footprint | Matched pattern | Correction | Affected |
|---|---|---|---|
| `USB_C_Receptacle_HRO_TYPE-C-31-M-12` | `^USB_C_Receptacle_HRO_TYPE-C-31-M-12*` | **+180°** | J1 (90→270) |
| `SOT-23-5` | `^SOT-23` | **−90°** | U1 (−90→180), U2 (0→270) |
| `SOT-23-6` | `^SOT-23` | **−90°** | U3 (−90→180) |

All other footprints (0805 R/C/L/LED, `D_SOD-123`, `L_Bourns_SRN6045TA`,
`FanPinHeader_1x04`, `SW_SPST_PTS810`) have no entry in the standard DB →
0° correction (KiCad and JLC orientations already agree for 2-pad passives).

**⚠️ Two footprints fall in gaps of the standard DB — verify manually:**

- **`JST_SH_SM04B-SRSS-TB…` (J2, J3):** the DB corrects `JST_GH`/`JST_PH` by
  +180° but has **no `JST_SH` rule**. JST SH parts commonly also need +180°.
  (Moot until an LCSC part is chosen; re-check orientation for the substitute.)
- **`ESP-WROOM-02` (U4):** the DB rule `^ESP32-W`→270° does **not** match this
  footprint's name (`ESP-WROOM-02`, not `ESP32-W…`), so no correction was
  applied. These modules typically need a correction; verify pin-1 orientation
  against the chosen module before ordering.

## Reproduce

```
kicad-cli sch export bom  … luftctl.kicad_sch      # -> bom_raw.csv
kicad-cli pcb export pos  --format csv --units mm --use-drill-file-origin … # -> pos_raw.csv
python3 match.py       # parametric + MPN verification against jlcparts
python3 gen_cpl.py     # rotation-corrected CPL
python3 finalize.py    # JLCPCB BOM + this report's table
kicad-cli pcb export gerbers/drill … # -> gerber/ -> luftctl-gerber.zip
```

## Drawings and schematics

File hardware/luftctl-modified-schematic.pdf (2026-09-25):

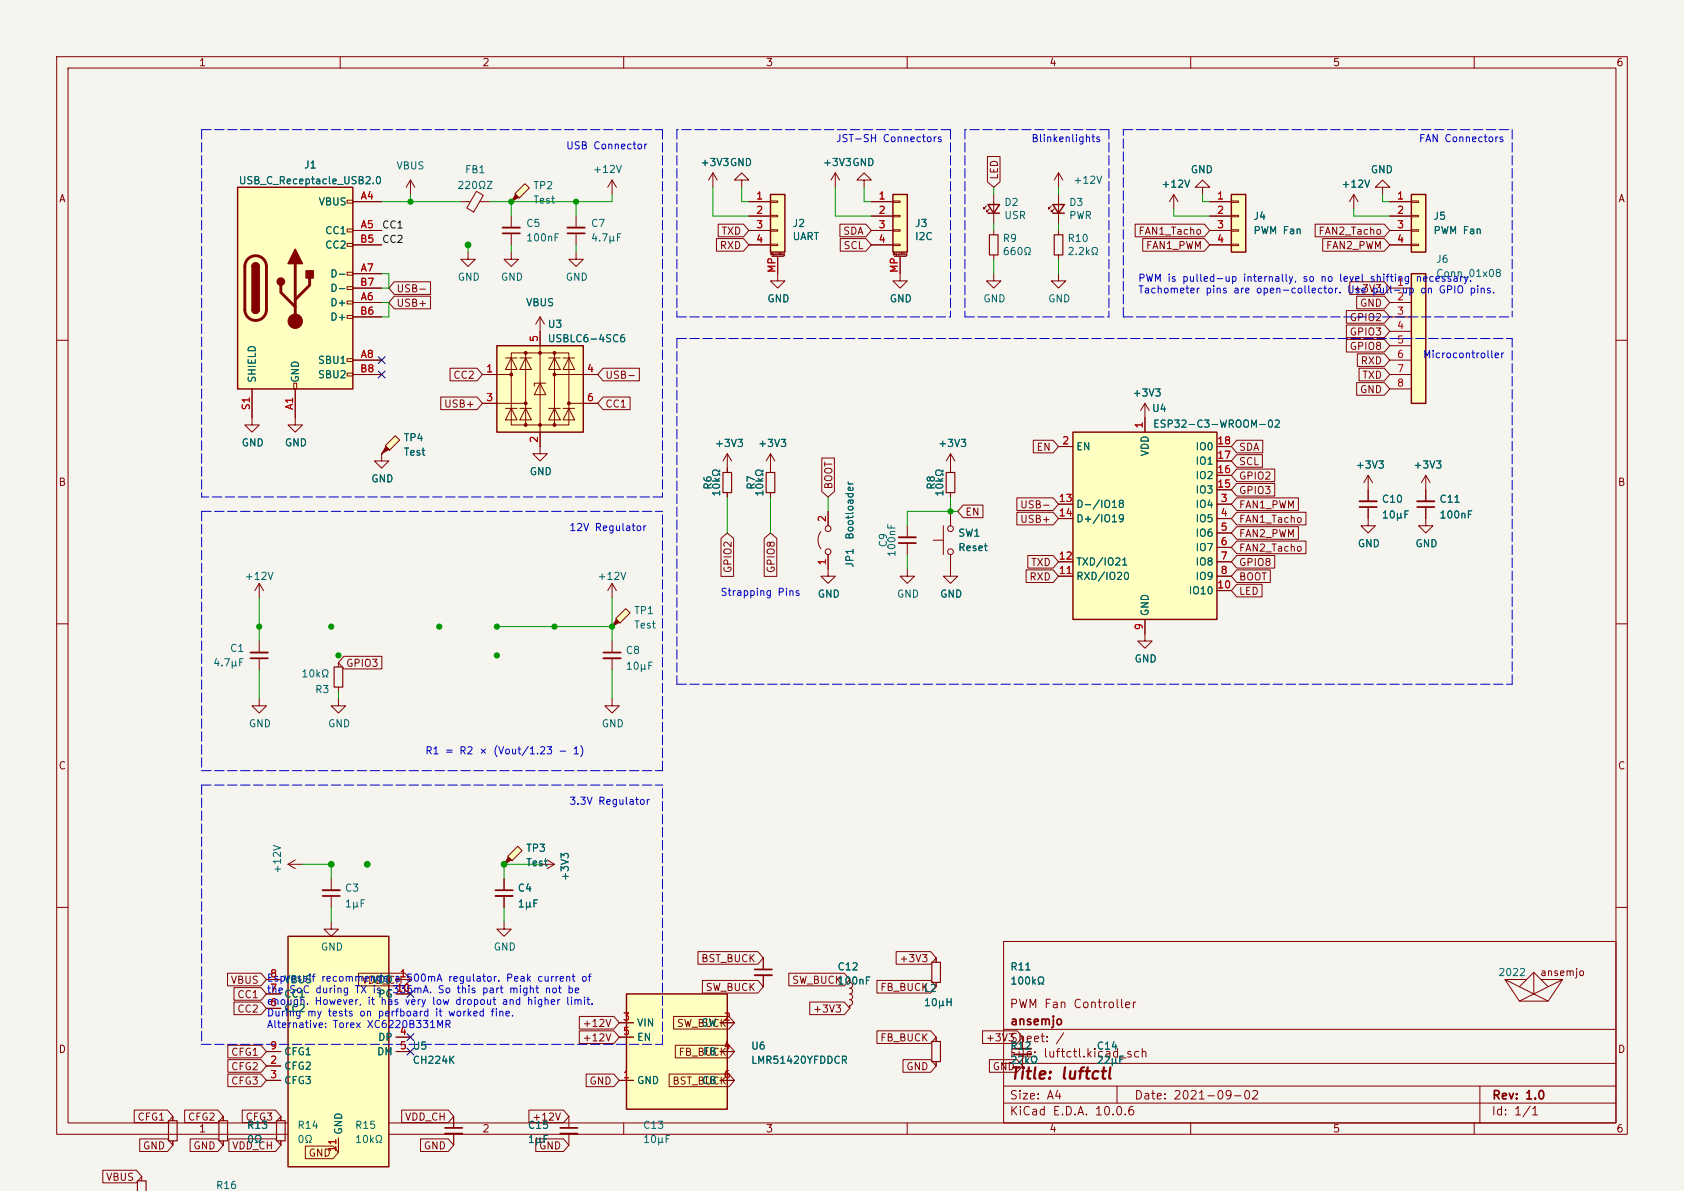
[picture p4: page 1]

R11 PWM Fan Controller ansemjo

enough. However, it has very low dropout and higher limit. During my tests on perfboard it worked fine. Alternative: Torex XC6220B331MR

VIN 3 | CB 6 FB 4 FB 4 FB_BUCK BST_BUCK
EN 5 GND 1 GND 1

Sheet: / R12 File: luftctl.kicad_sch 22kΩ 22kΩ | D Date: 2021-09-02

Size: A4 | Rev: 1.0
KiCad E.D.A. 10.0.6 | Id: 1/1

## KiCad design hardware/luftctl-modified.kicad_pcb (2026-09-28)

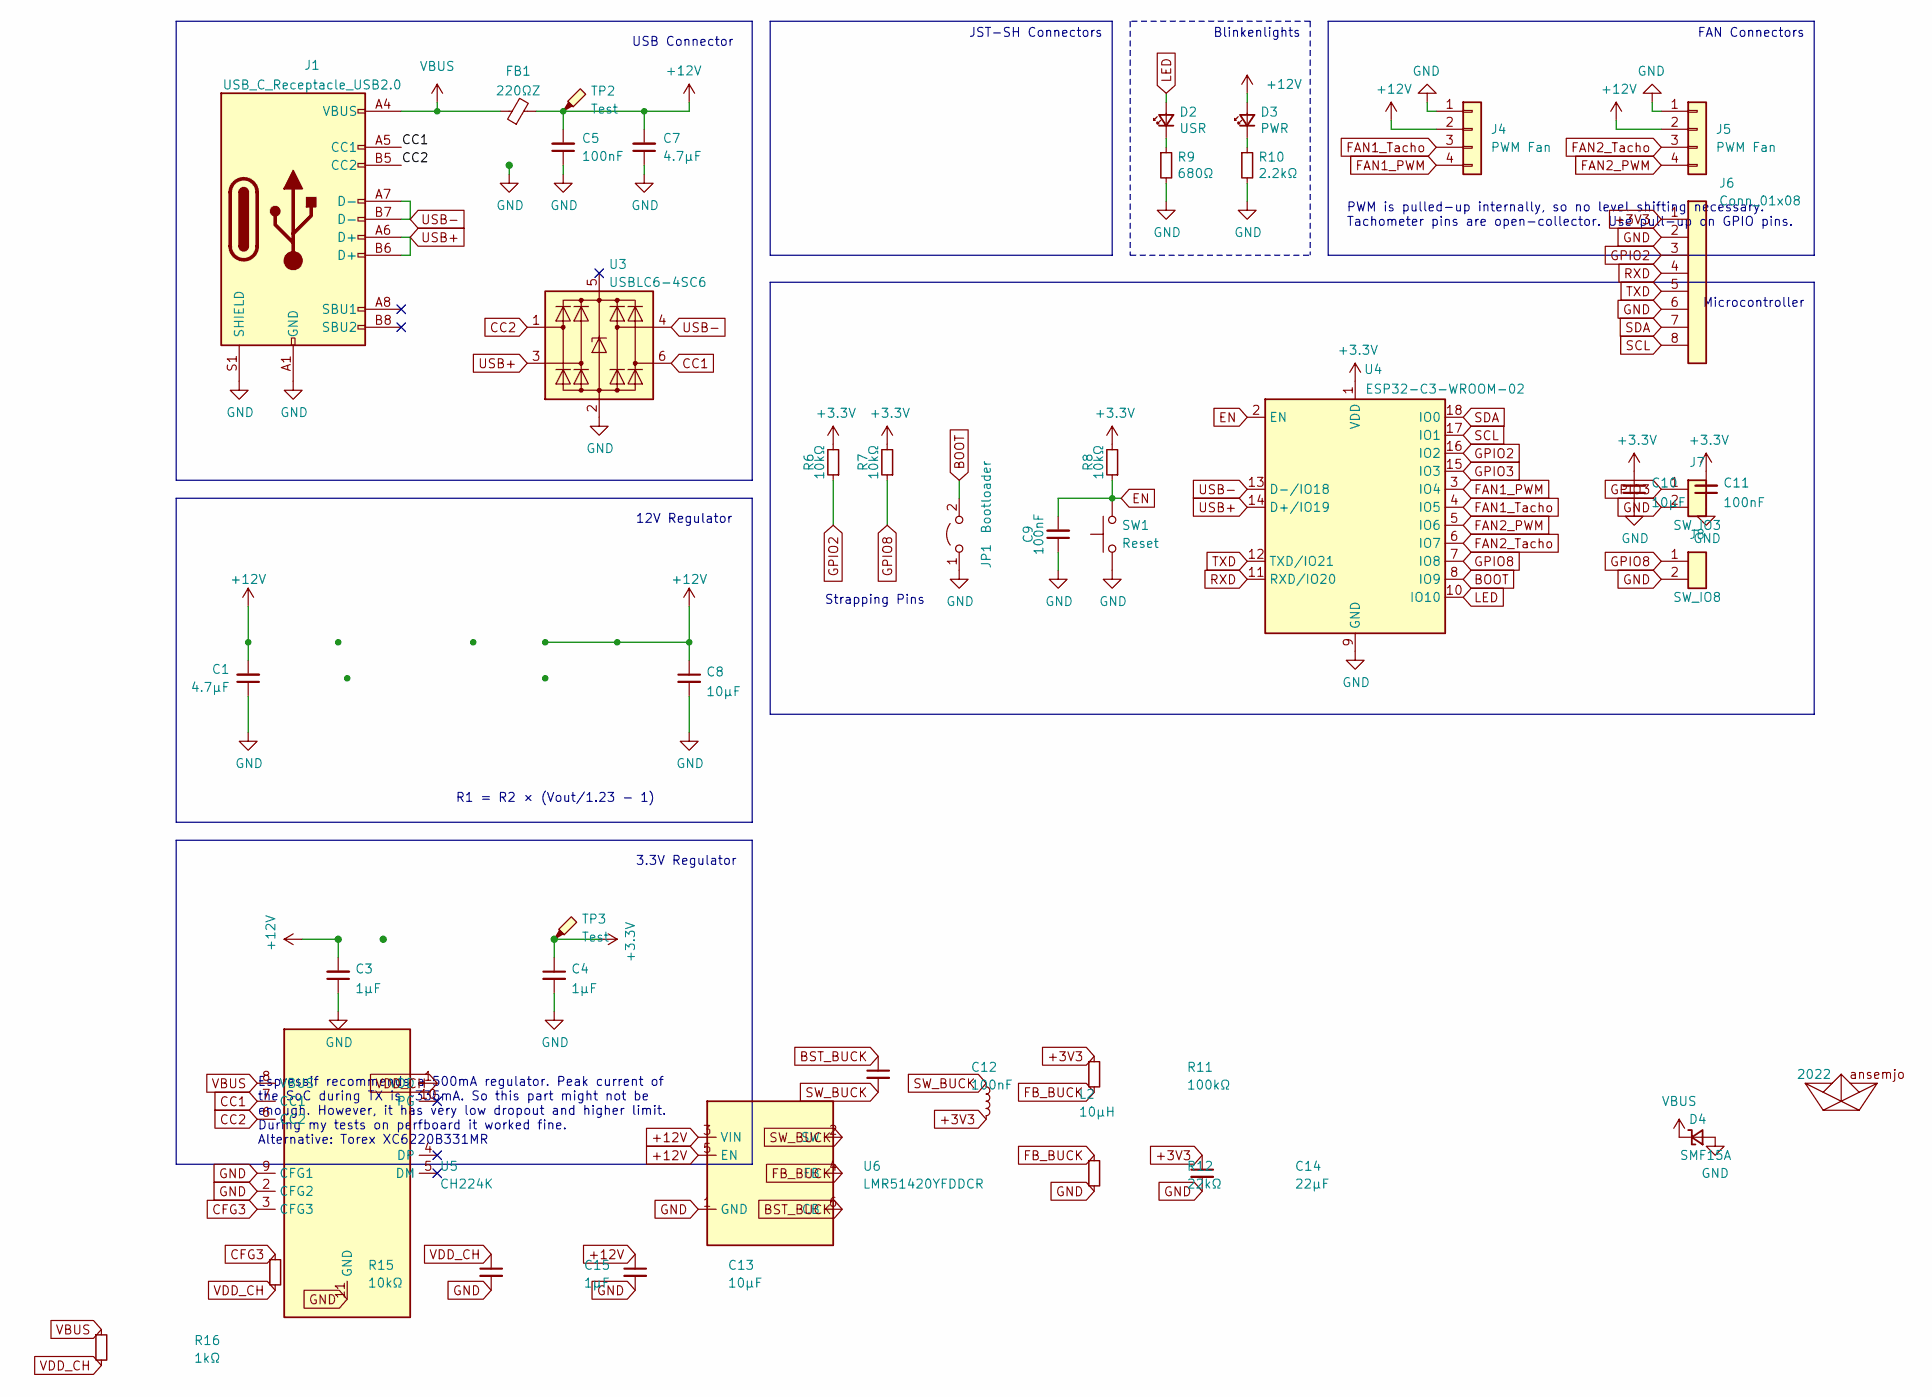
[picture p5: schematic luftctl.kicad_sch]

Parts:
A1: 2022; ahoi
C1, C7: 4.7µF; C_0805_2012Metric_Pad1.18x1.45mm_HandSolder
C3, C4, C15: 1µF; C_0805_2012Metric_Pad1.18x1.45mm_HandSolder
C5, C9, C11, C12: 100nF; C_0805_2012Metric_Pad1.18x1.45mm_HandSolder
C8, C10, C13: 10µF; C_0805_2012Metric_Pad1.18x1.45mm_HandSolder
C14: 22µF; C_0805_2012Metric_Pad1.18x1.45mm_HandSolder
D2: USR; LED_0805_2012Metric_Pad1.15x1.40mm_HandSolder
D3: PWR; LED_0805_2012Metric_Pad1.15x1.40mm_HandSolder
D4: SMF15A; D_SOD-123F
FB1: 220ΩZ; L_0805_2012Metric_Pad1.15x1.40mm_HandSolder
J1: USB_C_Receptacle_USB2.0; USB_C_Receptacle_HRO_TYPE-C-31-M-12
J4, J5: PWM Fan; FanPinHeader_1x04_P2.54mm_Vertical
J6: Conn_01x08; PinHeader_1x08_P2.54mm_Vertical
J7: SW_IO3; PinHeader_1x02_P2.54mm_Vertical
J8: SW_IO8; PinHeader_1x02_P2.54mm_Vertical
JP1: Bootloader; SW_SPST_TS-1088-xR020
L2: 10µH; L_Bourns_SRN6045TA
R6, R7, R8, R15: 10kΩ; R_0805_2012Metric_Pad1.20x1.40mm_HandSolder
R9: 680Ω; R_0805_2012Metric_Pad1.20x1.40mm_HandSolder
R10: 2.2kΩ; R_0805_2012Metric_Pad1.20x1.40mm_HandSolder
R11: 100kΩ; R_0805_2012Metric_Pad1.20x1.40mm_HandSolder
R12: 22kΩ; R_0805_2012Metric_Pad1.20x1.40mm_HandSolder
R16: 1kΩ; R_0805_2012Metric_Pad1.20x1.40mm_HandSolder
SW1: Reset; SW_SPST_TS-1088-xR020
TP2, TP3: Test; TestPoint_THTPad_D1.5mm_Drill0.7mm
U3: USBLC6-4SC6; SOT-23-6; MPN USBLC6-4SC6; Digi-Key_PN 497-4492-1-ND
U4: ESP32-C3-WROOM-02; ESP-WROOM-02
U5: CH224K; SSOP-10-1EP_3.9x4.9mm_P1mm_EP2.1x3.3mm
U6: LMR51420YFDDCR; SOT-23-6

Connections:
+12V: C1.2, C3.2, C5.2, C7.2, C8.1, C13.1, D3.2 (A), FB1.2, J4.2, J5.2, TP2.1, U6.3 (VIN), U6.5 (EN)
BOOT: JP1.2 (B), U4.8 (IO9)
BST_BUCK: C12.1, U6.6 (CB)
CC1: J1.A5 (CC1), U3.6 (I/O4), U5.7 (CC1)
CC2: J1.B5 (CC2), U3.1 (I/O1), U5.6 (CC2)
CFG3: R15.1, U5.3 (CFG3)
EN: C9.2, R8.1, SW1.2, U4.2 (EN)
FAN1_PWM: J4.4, U4.3 (IO4)
FAN1_Tacho: J4.3, U4.4 (IO5)
FAN2_PWM: J5.4, U4.5 (IO6)
FAN2_Tacho: J5.3, U4.6 (IO7)
FB_BUCK: R11.2, R12.1, U6.4 (FB)
GND: C1.1, C3.1, C4.2, C5.1, C7.1, C8.2, C9.1, C10.1, C11.1, C13.2, C14.2, C15.2, D4.2 (A), J1.A1 (GND), J1.A12 (GND), J1.B1 (GND), J1.B12 (GND), J1.S1 (SHIELD), J4.1, J5.1, J6.2, J6.6, J7.2, J8.2, JP1.1 (A), R9.2, R10.2, R12.2, SW1.1, U3.2 (GND), U4.9 (GND), U4.19 (GND), U5.2 (CFG2), U5.9 (CFG1), U5.11 (GND), U6.1 (GND)
GPIO2: J6.3, R6.1, U4.16 (IO2)
GPIO3: J7.1, U4.15 (IO3)
GPIO8: J8.1, R7.1, U4.7 (IO8)
LED: D2.2 (A), U4.10 (IO10)
unnamed: D2.1 (K), R9.1
unnamed: D3.1 (K), R10.1
RXD: J6.4, U4.11 (RXD/IO20)
SCL: J6.8, U4.17 (IO1)
SDA: J6.7, U4.18 (IO0)
SW_BUCK: C12.2, L2.1, U6.2 (SW)
TXD: J6.5, U4.12 (TXD/IO21)
USB+: J1.A6 (D+), J1.B6 (D+), U3.3 (I/O2), U4.14 (D+/IO19)
USB-: J1.A7 (D-), J1.B7 (D-), U3.4 (I/O3), U4.13 (D-/IO18)
VBUS: D4.1 (K), FB1.1, J1.A4 (VBUS), J1.A9 (VBUS), J1.B4 (VBUS), J1.B9 (VBUS), R16.1, U5.8 (VBUS)
VDD_CH: C15.1, R15.2, R16.2, U5.1 (VDD)

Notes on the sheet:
3.3V Regulator
PWM is pulled-up internally, so no level shifting necessary. Tachometer pins are open-collector. Use pull-up on GPIO pins.
12V Regulator
Strapping Pins
USB Connector
JST-SH Connectors
Microcontroller
FAN Connectors
R1 = R2 × (Vout/1.23 - 1)
Blinkenlights
Espressif recommends a 500mA regulator. Peak current of the SoC during TX is ~335mA. So this part might not be enough. However, it has very low dropout and higher limit. During my tests on perfboard it worked fine. Alternative: Torex XC6220B331MR

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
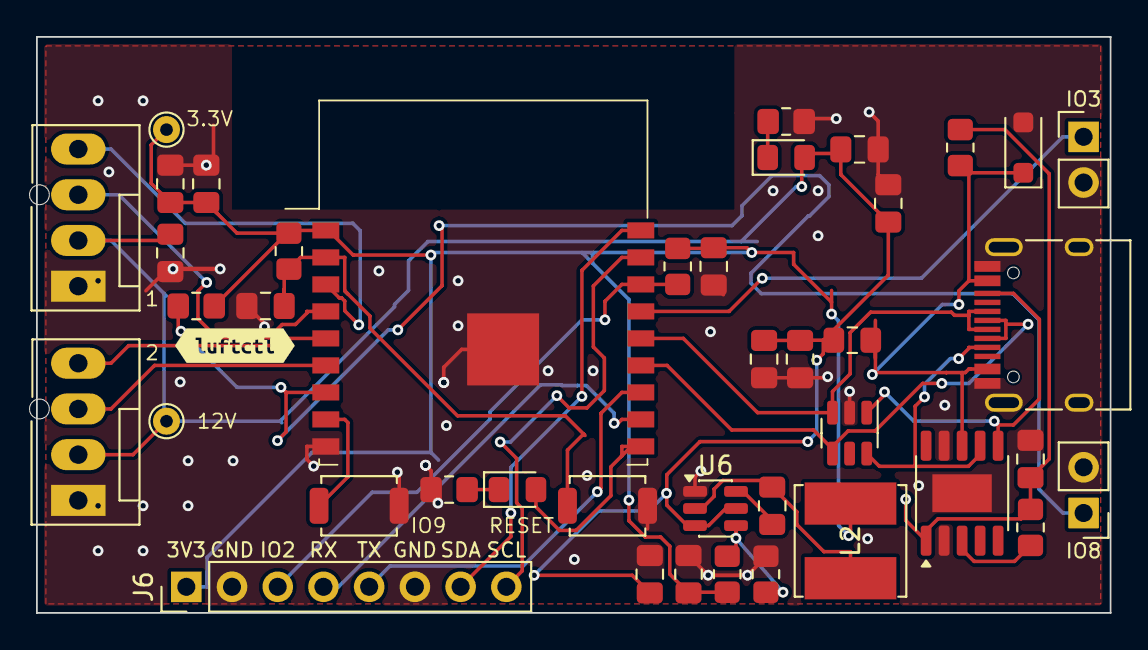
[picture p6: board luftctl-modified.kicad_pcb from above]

Board: 2 copper layers, 59.7 x 32.0 mm, 42 parts (0 on the bottom side), 29 nets.

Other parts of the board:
kibuzzard-61E47F36: G***; kibuzzard-61E47F36

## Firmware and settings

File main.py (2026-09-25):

# example code for ansemjo/luftctl
# 1. flash micropython from https://micropython.org/download/esp32c3-usb/
# 2. upload with `ampy -p /dev/ttyACM0 put main.py`

from machine import Pin as pin, PWM as pwm
from time import sleep, ticks_ms as ticks, ticks_diff as diff

# 12V now comes straight from USB-C PD (always on) - no boost enable anymore.
# GPIO3 is free and broken out on the J6 header (with GPIO2 and GPIO8).

# fan pwms
pwmfreq = 25000
f1 = pwm(pin(4, pin.OUT, pin.PULL_DOWN), pwmfreq)
f2 = pwm(pin(6, pin.OUT, pin.PULL_DOWN), pwmfreq)
f1.duty(0)
f2.duty(0)

# button
btn = pin(9, pin.IN, pin.PULL_UP)

# usr led
led = pwm(pin(10, pin.OUT, pin.PULL_DOWN), 10000)
led.duty(0)
def blink():
  led.duty(1023)
  sleep(0.06)
  led.duty(0)
  sleep(0.04)


# states to cycle through (fans stop at 0% pwm; 12V is always present)
states = [
  #  label  fan1   fan2  led
  (  "off",  0.00,  0.00,    0 ),
  (  "20%",  0.20,  0.20,  100 ),
  (  "45%",  0.45,  0.45,  300 ),
  (  "65%",  0.65,  0.65,  400 ),
  ( "100%",  1.00,  1.00,  800 ),
]

# button callback for state change
i = 0
now = ticks()
def nextstate(_):
  global i, now
  if diff(ticks(), now) < 300:
    print("debounce")
    return
  now = ticks()
  i = (i+1) % len(states)
  txt, d1, d2, l = states[i]
  print(f"[{i+1}/{len(states)}] {txt} {l}")
  f1.duty(int(d1*1023))
  f2.duty(int(d2*1023))
  blink()
  led.duty(l)

# register callback on falling edge / button press
btn.irq(trigger=pin.IRQ_FALLING, handler=nextstate)

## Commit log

2026-09-25 Add USB-C PD 12V input + GPIO breakout header (routed board + fab files)
    Two hardware modifications to luftctl:
    1. Power the fans from 12V negotiated over USB-C Power Delivery instead of
    boosting 5V on-board. Removes the boost (U1 LMR62014), its inductor,
    Schottky, feedback divider and the 5.1k CC pull-downs; adds a CH224K PD
    trigger (U5) and an LMR51420 buck (U6, 12V->3V3) for logic. The +5V rail is
    merged into +12V and the J2/J3 connector power pins move to +3V3.
    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
    [bom_raw.csv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]
2026-09-25 CH224K: fix 12V CFG straps + VDD supply per datasheet; re-route
    Datasheet research (WCH CH224 V2.0; TI LMR51420 SLUSEF6C), cross-verified,
    corrected two bugs in the CH224K PD-trigger wiring that would have made the
    board negotiate 9V with an unpowered controller:
    - CFG3 must be pulled HIGH (to VDD) for 12V, not strapped to GND. CH224K has no
    internal CFG pull-ups, so R15 is changed from a 0R GND strap to a 10k pull-up
    to VDD (R15/CFG3 -> VDD_CH). CFG1/CFG2 stay strapped to GND (R13/R14 = 0R):
    CFG1,CFG2,CFG3 = 0,0,1 = 12V.
    - VDD (pin 1) needs a series feed from VBUS; add R16 = 1k (VBUS -> VDD_CH) with
    the existing C15 1uF bypass. Previously VDD only had the cap (never powered).
    LMR5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
    [luftctl-mod-bom.csv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]
2026-09-26 Fix doubled-C LCSC prefix in modified assembly BOM
    Verification (independent adversarial audit) caught a BOM-generation bug: the
    LCSC Part # column was written as "CC6654733" (double C) because the assignment
    map already includes the "C" prefix and the writer prepended another. JLCPCB
    would fail to match every populated part. Corrected all 19 populated rows to the
    valid single-C format (C6654733, C7296200, ...), each verified in-stock in the
    jlcparts snapshot. Fixed the generator script too.
    [luftctl-mod-bom.csv]
2026-09-27 Fix USBLC6 on 12V VBUS, add VBUS TVS, switch to JLCPCB Basic parts
    - U3 (USBLC6) pin 5 disconnected from VBUS. VBUS is 12V after PD
    negotiation and the USBLC6 supply-pin clamp conducts from ~6V. Left
    floating (not +3V3) since CC1/CC2 on U3 sit near 5V.
    - Add D4 SMF15A (15V standoff) TVS from VBUS to GND, above J1.
    - SW1/JP1 buttons: PTS810 -> TS-1088-AR02016 (C720477, JLCPCB Basic).
    - Re-source all passives/LEDs to JLCPCB Basic parts; R9 660R -> 680R.
    - U4 -> ESP32-C3-WROOM-02-N4 (C2934560, PCB antenna, in stock).
    - Pin headers J4/J5/J6 dropped from the assembly BOM (hand-soldered).
    - Local re-route; DRC 0 unconnected, no shorts; board matches schematic.
    - MODIFICATIONS.md: sourcing note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
    [luftctl-mod-bom.csv, luftctl-modified.kicad_pcb, luftctl.kicad_sch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]
2026-09-27 Fix TP2 silkscreen: 12V, not 3V3
    TP2 is on the +12V rail (the old +5V rail became +12V with the PD input),
    but its label had been changed to "3V3".
    [luftctl-modified.kicad_pcb]
2026-09-28 BOM: L2 -> C2046332 (SRN6045TA), FB1 -> C85840 (BLM21PG221SN1D)
    The old listings have no JLCPCB footprint data, so the placement
    preview could not place them. Same footprints.
    [luftctl-mod-bom.csv]
2026-09-28 Remove J2/J3 JST-SH connectors; J6 becomes 1x10 with SDA/SCL and pin labels
    UART was already on J6 and flashing/logs go over native USB, so J2 was
    redundant. SDA (GPIO0) and SCL (GPIO1) move from J3 to J6 pins 9/10.
    J6: 3V3, GND, IO2, IO3, IO8, RX, TX, GND, SDA, SCL, labelled on silk.
    Local re-route; DRC 0 unconnected, no new violations; board matches
    schematic. Drops the C160404 Extended line from the BOM.
    [luftctl-mod-bom.csv, luftctl-modified.kicad_pcb, luftctl.kicad_sch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]
2026-09-28 Compact layout: 56.7 x 32.1 mm, centred on fan headers and USB-C
    - Outline centred on the fan headers (y 62.45); J1 moved down 5 mm to match.
    - J6 along the bottom edge; buck and CH224K groups packed beside SW1 and
    under J1; D4/R16 above J1. TP1/TP4 removed.
    - GND poured on both layers with via stitching; antenna keep-out extended.
    - Re-routed; DRC 0 unconnected, no new violations; board matches schematic.
    - CPL regenerated with JLCPCB rotation corrections; gerbers regenerated.
    [luftctl-modified.kicad_pcb, luftctl.kicad_sch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]
2026-09-28 Back silkscreen: 2026 elbob
    [luftctl-modified.kicad_pcb]
2026-09-28 Add J7/J8 switch headers (GPIO3, GPIO8) beside USB-C
    - J7 (GPIO3+GND) above and J8 (GPIO8+GND) below the USB-C port on the
    right edge; ESPHome Switch 1/Switch 2 binary sensors with pull-ups.
    - Remove R3 (old GPIO3 pull-down) so the switch input can idle high.
    - J6 back to 8 pins (3V3, GND, IO2, RX, TX, GND, SDA, SCL).
    - Tie CH224K CFG1/CFG2 directly to GND; drop R13/R14 0R straps.
    - Edge no-track strips; FAN1_Tacho re-routed off the board edge.
    - DRC 0 unconnected, no new errors; board matches schematic.
    [luftctl-mod-bom.csv, luftctl-modified.kicad_pcb, luftctl.kicad_sch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]
2026-09-28 J7/J8 vertical along the USB-C edge; board 3 mm wider (59.75 x 32.1)
    Both switch headers now stand vertically on the right edge above and below
    USB-C (GND pins nearest the port). Right edge moved out 3 mm; J1 moved with
    it. Re-routed; DRC 0 unconnected, no new violations; CPL/gerbers updated.
    [luftctl-modified.kicad_pcb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]
